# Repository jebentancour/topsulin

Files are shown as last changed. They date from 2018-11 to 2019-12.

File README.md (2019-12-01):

# Topsulin

## Software

### BLE Services and Characteristics

|GATT Services |GATT Characteristics |Description |
|---|---|---|
|**Glucose** |0x1808 |Servicio estándar para glucómetros |
|0x2A18 |**Glucose Measurement** |Valores de glucemia |
|0x2A34 |**Glucose Measurement Context** |Información adicional (CHO e insulina) |
|0x2A51 |**Glucose Feature** |Información sobre features soportadas |
|0x2A52 |**Record Access Control Point** |Punto de control de acceso del registro  |
|**Topsulin**  |0xF65D |Servicio específico de Topsulin |
|0xF65E |**Configuration** |Configuración de preferencias de usuario |
|0xF65F |**Name** |Nombre para mostrar |
|0xF660 |**Time** |Fecha y hora |
|0xF661 |**Calculator** |Parámetros para el calculador de bolos |
|0xF662 |**Insulin** |Tipo, capacidad y cantidad restante |
|0xF663 |**Device** |Información sobre el dispositivo |

Base UUID para Topsulin Services y Characteristics 0x3419-XXXX-1505-31A7-EC4D-449B-0752-1104

#### Glucose Service

Según el servicio estándar [Glucose Service Specification](https://www.bluetooth.com/specifications/gatt/viewer?attributeXmlFile=org.bluetooth.service.glucose.xml)

Definimos que 1 U de insulina se representa como 10 ml.

```c
/**@brief Glucose feature */
#define BLE_GLS_FEATURE_LOW_BATT                       0x0001  /**< Low Battery Detection During Measurement Supported */
#define BLE_GLS_FEATURE_MALFUNC                        0x0002  /**< Sensor Malfunction Detection Supported */
#define BLE_GLS_FEATURE_SAMPLE_SIZE                    0x0004  /**< Sensor Sample Size Supported */
#define BLE_GLS_FEATURE_INSERT_ERR                     0x0008  /**< Sensor Strip Insertion Error Detection Supported */
#define BLE_GLS_FEATURE_TYPE_ERR                       0x0010  /**< Sensor Strip Type Error Detection Supported */
#define BLE_GLS_FEATURE_RES_HIGH_LOW                   0x0020  /**< Sensor Result High-Low Detection Supported */
#define BLE_GLS_FEATURE_TEMP_HIGH_LOW                  0x0040  /**< Sensor Temperature High-Low Detection Supported */
#define BLE_GLS_FEATURE_READ_INT                       0x0080  /**< Sensor Read Interrupt Detection Supported */
#define BLE_GLS_FEATURE_GENERAL_FAULT                  0x0100  /**< General Device Fault Supported */
#define BLE_GLS_FEATURE_TIME_FAULT                     0x0200  /**< Time Fault Supported */
#define BLE_GLS_FEATURE_MULTI_BOND                     0x0400  /**< Multiple Bond Supported */

/**@brief Glucose measurement flags */
#define BLE_GLS_MEAS_FLAG_TIME_OFFSET                  0x01    /**< Time Offset Present */
#define BLE_GLS_MEAS_FLAG_CONC_TYPE_LOC                0x02    /**< Glucose Concentration, Type, and Sample Location Present */
#define BLE_GLS_MEAS_FLAG_UNITS_KG_L                   0x00    /**< Glucose Concentration Units kg/L */
#define BLE_GLS_MEAS_FLAG_UNITS_MOL_L                  0x04    /**< Glucose Concentration Units mol/L */
#define BLE_GLS_MEAS_FLAG_SENSOR_STATUS                0x08    /**< Sensor Status Annunciation Present */
#define BLE_GLS_MEAS_FLAG_CONTEXT_INFO                 0x10    /**< Context Information Follows */

/**@brief Glucose measurement type */
#define BLE_GLS_MEAS_TYPE_CAP_BLOOD                    1       /**< Capillary whole blood */
#define BLE_GLS_MEAS_TYPE_CAP_PLASMA                   2       /**< Capillary plasma */
#define BLE_GLS_MEAS_TYPE_VEN_BLOOD                    3       /**< Venous whole blood */
#define BLE_GLS_MEAS_TYPE_VEN_PLASMA                   4       /**< Venous plasma */
#define BLE_GLS_MEAS_TYPE_ART_BLOOD                    5       /**< Arterial whole blood */
#define BLE_GLS_MEAS_TYPE_ART_PLASMA                   6       /**< Arterial plasma */
#define BLE_GLS_MEAS_TYPE_UNDET_BLOOD                  7       /**< Undetermined whole blood */
#define BLE_GLS_MEAS_TYPE_UNDET_PLASMA                 8       /**< Undetermined plasma */
#define BLE_GLS_MEAS_TYPE_FLUID                        9       /**< Interstitial fluid (ISF) */
#define BLE_GLS_MEAS_TYPE_CONTROL                      10      /**< Control solution */

/**@brief Glucose measurement location */
#define BLE_GLS_MEAS_LOC_FINGER                        1       /**< Finger */
#define BLE_GLS_MEAS_LOC_AST                           2       /**< Alternate Site Test (AST) */
#define BLE_GLS_MEAS_LOC_EAR                           3       /**< Earlobe */
#define BLE_GLS_MEAS_LOC_CONTROL                       4       /**< Control solution */
#define BLE_GLS_MEAS_LOC_NOT_AVAIL                     15      /**< Sample Location value not available */

/**@brief Glucose sensor status annunciation */
#define BLE_GLS_MEAS_STATUS_BATT_LOW                   0x0001  /**< Device battery low at time of measurement */
#define BLE_GLS_MEAS_STATUS_SENSOR_FAULT               0x0002  /**< Sensor malfunction or faulting at time of measurement */
#define BLE_GLS_MEAS_STATUS_SAMPLE_SIZE                0x0004  /**< Sample size for blood or control solution insufficient at time of measurement */
#define BLE_GLS_MEAS_STATUS_STRIP_INSERT               0x0008  /**< Strip insertion error */
#define BLE_GLS_MEAS_STATUS_STRIP_TYPE                 0x0010  /**< Strip type incorrect for device */
#define BLE_GLS_MEAS_STATUS_RESULT_HIGH                0x0020  /**< Sensor result higher than the device can process */
#define BLE_GLS_MEAS_STATUS_RESULT_LOW                 0x0040  /**< Sensor result lower than the device can process */
#define BLE_GLS_MEAS_STATUS_TEMP_HIGH                  0x0080  /**< Sensor temperature too high for valid test/result at time of measurement */
#define BLE_GLS_MEAS_STATUS_TEMP_LOW                   0x0100  /**< Sensor temperature too low for valid test/result at time of measurement */
#define BLE_GLS_MEAS_STATUS_STRIP_PULL                 0x0200  /**< Sensor read interrupted because strip was pulled too soon at time of measurement */
#define BLE_GLS_MEAS_STATUS_GENERAL_FAULT              0x0400  /**< General device fault has occurred in the sensor */
#define BLE_GLS_MEAS_STATUS_TIME_FAULT                 0x0800  /**< Time fault has occurred in the sensor and time may be inaccurate */

/**@brief Glucose measurement context flags */
#define BLE_GLS_CONTEXT_FLAG_CARB                      0x01    /**< Carbohydrate id and carbohydrate present */
#define BLE_GLS_CONTEXT_FLAG_MEAL                      0x02    /**< Meal present */
#define BLE_GLS_CONTEXT_FLAG_TESTER                    0x04    /**< Tester-health present */
#define BLE_GLS_CONTEXT_FLAG_EXERCISE                  0x08    /**< Exercise duration and exercise intensity present */
#define BLE_GLS_CONTEXT_FLAG_MED                       0x10    /**< Medication ID and medication present */
#define BLE_GLS_CONTEXT_FLAG_MED_KG                    0x00    /**< Medication value units, kilograms */
#define BLE_GLS_CONTEXT_FLAG_MED_L                     0x20    /**< Medication value units, liters */
#define BLE_GLS_CONTEXT_FLAG_HBA1C                     0x40    /**< Hba1c present */
#define BLE_GLS_CONTEXT_FLAG_EXT                       0x80    /**< Extended flags present */

/**@brief Glucose measurement context carbohydrate ID */
#define BLE_GLS_CONTEXT_CARB_BREAKFAST                 1       /**< Breakfast */
#define BLE_GLS_CONTEXT_CARB_LUNCH                     2       /**< Lunch */
#define BLE_GLS_CONTEXT_CARB_DINNER                    3       /**< Dinner */
#define BLE_GLS_CONTEXT_CARB_SNACK                     4       /**< Snack */
#define BLE_GLS_CONTEXT_CARB_DRINK                     5       /**< Drink */
#define BLE_GLS_CONTEXT_CARB_SUPPER                    6       /**< Supper */
#define BLE_GLS_CONTEXT_CARB_BRUNCH                    7       /**< Brunch */

/**@brief Glucose measurement context meal */
#define BLE_GLS_CONTEXT_MEAL_PREPRANDIAL               1       /**< Preprandial (before meal) */
#define BLE_GLS_CONTEXT_MEAL_POSTPRANDIAL              2       /**< Postprandial (after meal) */
#define BLE_GLS_CONTEXT_MEAL_FASTING                   3       /**< Fasting */
#define BLE_GLS_CONTEXT_MEAL_CASUAL                    4       /**< Casual (snacks, drinks, etc.) */
#define BLE_GLS_CONTEXT_MEAL_BEDTIME                   5       /**< Bedtime */

/**@brief Glucose measurement context tester */
#define BLE_GLS_CONTEXT_TESTER_SELF                    1       /**< Self */
#define BLE_GLS_CONTEXT_TESTER_PRO                     2       /**< Health care professional */
#define BLE_GLS_CONTEXT_TESTER_LAB                     3       /**< Lab test */
#define BLE_GLS_CONTEXT_TESTER_NOT_AVAIL               15      /**< Tester value not available */

/**@brief Glucose measurement context health */
#define BLE_GLS_CONTEXT_HEALTH_MINOR                   1       /**< Minor health issues */
#define BLE_GLS_CONTEXT_HEALTH_MAJOR                   2       /**< Major health issues */
#define BLE_GLS_CONTEXT_HEALTH_MENSES                  3       /**< During menses */
#define BLE_GLS_CONTEXT_HEALTH_STRESS                  4       /**< Under stress */
#define BLE_GLS_CONTEXT_HEALTH_NONE                    5       /**< No health issues */
#define BLE_GLS_CONTEXT_HEALTH_NOT_AVAIL               15      /**< Health value not available */

/**@brief Glucose measurement context medication ID */
#define BLE_GLS_CONTEXT_MED_RAPID                      1       /**< Rapid acting insulin */
#define BLE_GLS_CONTEXT_MED_SHORT                      2       /**< Short acting insulin */
#define BLE_GLS_CONTEXT_MED_INTERMED                   3       /**< Intermediate acting insulin */
#define BLE_GLS_CONTEXT_MED_LONG                       4       /**< Long acting insulin */
#define BLE_GLS_CONTEXT_MED_PREMIX                     5       /**< Pre-mixed insulin */

/**@brief SFLOAT format (IEEE-11073 16-bit FLOAT, meaning 4 bits for exponent (base 10) and 12 bits mantissa) */
typedef struct
{
  int8_t exponent;                                             /**< Base 10 exponent, should be using only 4 bits */
  int16_t mantissa;                                            /**< Mantissa, should be using only 12 bits */
} sfloat_t;
```

Los enteros de 16 bits se codifican de manera que el byte más alto va primero. El número 250 en hexadecimal es 0x00FA, sin embargo en BLE se lee el byte 0xFA00.

El sfloat se usa para guardar un número con coma en 16 bits, los primeros 12 bits son la mantisa y los otros 4 el exponente.

```c
uint16_t encode_sfloat(sfloat_t sf)
{
    uint16_t dec;
    dec = ((sf.exponent << 12) & 0xF000) | ((sf.mantissa <<  0) & 0x0FFF);
    return dec;
}

sfloat_t decode_sfloat(uint16_t u)
{
    sfloat_t sf;
    sf.exponent = (u & 0xF000) >> 12;
    sf.mantissa = (u & 0x0FFF) >> 0;
    return sf;
}
```

#### Topsulin Service

[Characteristic Format Types](https://www.bluetooth.com/specifications/assigned-numbers/format-types)

|Characteristic |Format |Value |Default |
|---|---|---|---|
|**Configuration** | | | |
|Registro de glucemia |bit0 |0 No, 1 Si |Si |
|Registro de insulina |bit1 |0 No, 1 Si |Si |
|Registro de CHO |bit2 |0 No, 1 Si |Si |
|Invertir los colores de la pantalla |bit3 |0 Fondo blanco, 1 Fondo negro |Fondo blanco |
|Unidades de glucemia |bit4 |0 kg/L, 1 mol/L |kg/L |
|Calculador de bolo |bit5 |0 Desactivado, 1 Activado |Desactivado |
|Orientación de pantalla |bit6 |0 Diestro, 1 Zurdo |Diestro |
|Unidades de CHO |bit7 |0 CHO en g, 1 CHO en porciones |CHO en g |
|Equivalencia entre gramos y porciones |uint16 |Peso en g de una porción |250 g |
|Incremento de CHO |uint8  |Paso de ingreso de CHO en g |5 g |
|Incremento de insulina |uint8  |Paso de ingreso de insulina x10 |10 (equivale a 1U) |
|**Name** | | | |
|Nombre para mostrar |uint8  |String de largo máximo 20 UTF-8 |Glucosee |
|**Time** | | | |
|Hora y fecha del dispositivo |time |[Time Characteristic](https://www.bluetooth.com/specifications/gatt/viewer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) |01/01/19 12:00:00 |
|**Calculator** | | | |
|Nivel bajo |sfloat |Nivel de glucemia baja en kg/L |90x10^-5 kg/L |
|Nivel alto |sfloat |Nivel de glucemia alta en kg/L |150x10^-5 kg/L |
|Sensibilidad |uint16 |Cada cuántos CHO en g incremento insulina |15 g |
|Corrección de hiperglucemia |sfloat |Cada cuántos kg/L de hiper incremento insulina |50x10^-5 kg/L |
|**Insulin** | | | |
|Tipo de insulina |uint8  |Medication ID from Glucose Service |BLE_GLS_CONTEXT_MED_RAPID |
|Capacidad de la lapicera |uint16 |U de insulina en una lapicera nueva|300 U |
|Capacidad restante de la lapicera |uint16 |U de insulina restantes |120 U |
|Comienzo de acción |uint16 |En minutos |30 m |
|Acción máxima |uint16 |En minutos |120 m |
|Duración de la acción |uint16 |En minutos |360 m |
|**Device** | | | |
|Firmware |uint8  |Versión de firmware |1 |
|Serial Number |uint16 |Número de serie |1 |
|Battery |uint16 |Voltaje de la batería en mV |Cerca de 3300 mV |

## Board

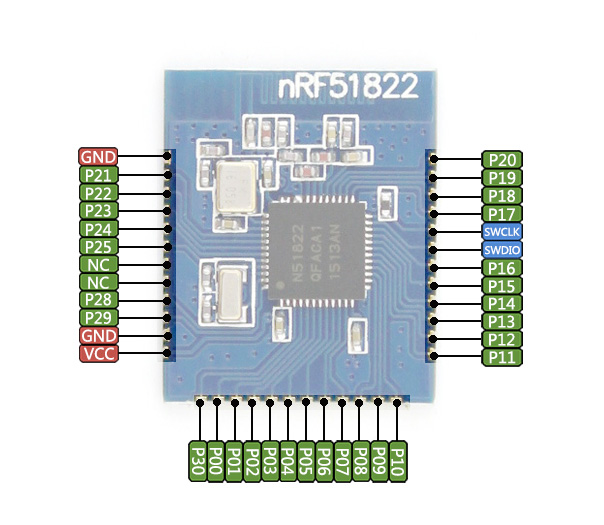
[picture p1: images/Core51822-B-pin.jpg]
pinout


## Encoder

|nRF pin|Use  |
|---|-----|
|01 |A |
|00 |B |
|30 |SW |

## Display

|nRF pin|Use  |
|---|-----|
|21 |MOSI |
|22 |CLK  |
|23 |CS |
|24 |DC |
|25 |RST  |
|28 |BUSY |

## SoC

SoC [nRF51822](https://www.nordicsemi.com/eng/nordic/download_resource/62726/14/39584073/13358) QFACA10 (256kB flash, 32 kB RAM)

[INFOCENTER](http://infocenter.nordicsemi.com)

|ID |Base address |Peripheral  |Instance |Description |Used by |
|---|---|---|---|---|---|
|0  |0x40000000 |POWER |POWER |Power Control. |SoftDevice |
|0  |0x40000000 |CLOCK |CLOCK |Clock Control. |SoftDevice |
|0  |0x40000000 |MPU |MPU |Memory Protection Unit. |SoftDevice |
|1  |0x40001000 |RADIO |RADIO |2.4 GHz Radio. |SoftDevice |
|2  |0x40002000 |UART |UART0 |Universal Asynchronous Receiver/Transmitter. | |
|3  |0x40003000 |SPI |SPI0 |SPI Master. |EPD (SPI) |
|3  |0x40003000 |TWI |TWI0 |I2C compatible Two-Wire Interface 0. |EPD (SPI) |
|4  |0x40004000 |SPIS |SPIS1 |SPI Slave. | |
|4  |0x40004000 |SPI |SPI1 |SPI Master. | |
|4  |0x40004000 |TWI |TWI1 |I2C compatible Two-Wire Interface 1. | |
|6  |0x40006000 |GPIOTE |GPIOTE |GPIO Task and Events. | |
|7  |0x40007000 |ADC |ADC |Analog to Digital Converter. |Battery |
|8  |0x40008000 |TIMER |TIMER0 |Timer/Counter 0. |SoftDevice |
|9  |0x40009000 |TIMER |TIMER1 |Timer/Counter 1. | |
|10 |0x4000A000 |TIMER |TIMER2 |Timer/Counter 2. | |
|11 |0x4000B000 |RTC |RTC0 |Real Time Counter 0. |SoftDevice |
|12 |0x4000C000 |TEMP |TEMP |Temperature Sensor. |SoftDevice |
|13 |0x4000D000 |RNG |RNG |Random Number Generator. |SoftDevice |
|14 |0x4000E000 |ECB |ECB |Crypto AES ECB. |SoftDevice |
|15 |0x4000F000 |CCM |CCM |AES Crypto CCM. |SoftDevice |
|15 |0x4000F000 |AAR |AAR |Accelerated Address Resolver. |SoftDevice |
|16 |0x40010000 |WDT |WDT |Watchdog Timer. | |
|17 |0x40011000 |RTC |RTC1 |Real Time Counter 1. |Timer library |
|18 |0x40012000 |QDEC |QDEC |Quadrature Decoder. |Encoder |
|19 |0x40013000 |LPCOMP |LPCOMP |Low Power Comparator. | |
|20 |0x40014000 |SWI |SWI0 |Software interrupt. |Timer library |
|21 |0x40015000 |SWI |SWI1 |Software interrupt. |SoftDevice |
|22 |0x40016000 |SWI |SWI2 |Software interrupt |SoftDevice |
|23 |0x40017000 |SWI |SWI3 |Software interrupt. | |
|24 |0x40018000 |SWI |SWI4 |Software interrupt. |SoftDevice |
|25 |0x40019000 |SWI |SWI5 |Software interrupt. |SoftDevice |
|30 |0x4001E000 |NVMC |NVMC |Non-Volatile Memory Controller. |SoftDevice |
|31 |0x4001F000 |PPI |PPI |Programmable Peripheral Interconnect. | |
|NA |0x50000000 |GPIO |GPIO |General Purpose Input and Output. |Gpio |
|NA |0x10000000 |FICR |FICR |Factory Information Configuration Registers. |SoftDevice |
|NA |0x10001000 |UICR |UICR |User Information Configuration Registers. |SoftDevice |

## EPD

[Image file to embedded C/C++ code](https://digole.com/tools/PicturetoC_Hex_converter.php)

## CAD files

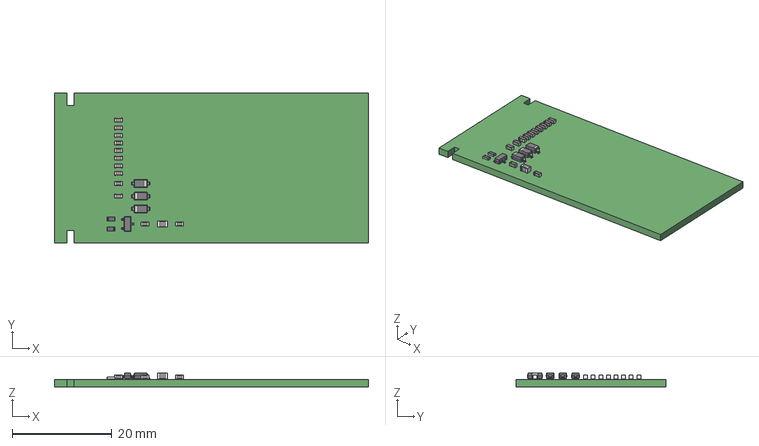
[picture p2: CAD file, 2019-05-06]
pcb/pcb_topsulin_base.step
63.0 x 30.0 x 2.90 mm

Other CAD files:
pcb/pcb_topsulin.step

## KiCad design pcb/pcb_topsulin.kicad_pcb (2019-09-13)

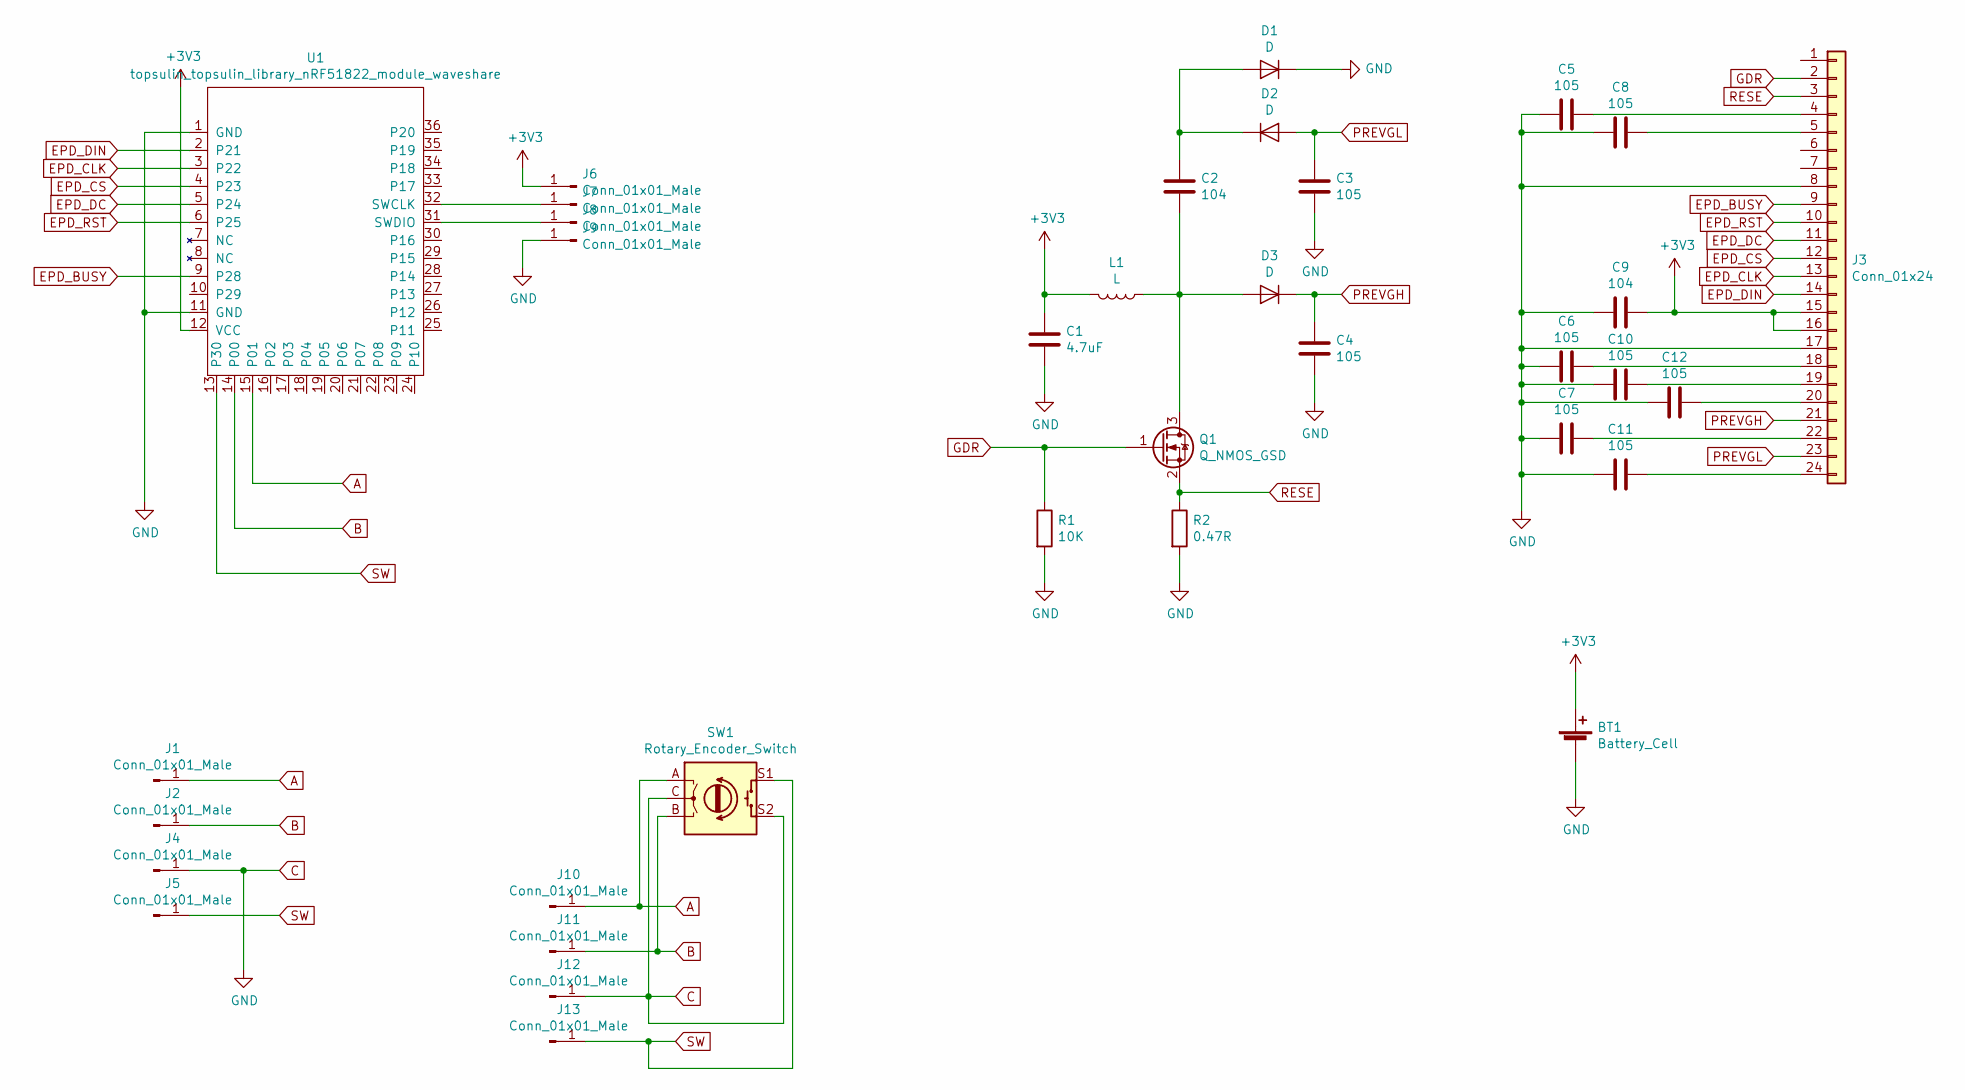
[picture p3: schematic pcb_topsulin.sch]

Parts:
BT1: Battery_Cell; BatteryHolder_Keystone_1058_1x2032
C1: 4.7uF; C_0603_1608Metric
C2, C9: 104; C_0603_1608Metric
C3, C4, C5, C6, C7, C8, C10, C11, C12: 105; C_0603_1608Metric
D1, D2, D3: D; D_SOD-123
J1, J2, J4, J5, J10, J11, J12, J13: Conn_01x01_Male; TestPoint_Pad_2.0x2.0mm
J3: Conn_01x24; e-paper-2in13-flex
J6, J7, J8, J9: Conn_01x01_Male; TestPoint_Pad_1.0x1.0mm
L1: L; L_0805_2012Metric
Q1: Q_NMOS_GSD; SOT-23
R1: 10K; R_0603_1608Metric
R2: 0.47R; R_0603_1608Metric
SW1: Rotary_Encoder_Switch; RotaryEncoder_Alps_EC12E-Switch_Vertical_H20mm
U1: topsulin_topsulin_library_nRF51822_module_wavesha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; nRF51822_module_waveshare_footprint

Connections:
+3V3: BT1.1 (+), C1.1, C9.1, J3.15, J3.16, J6.1, L1.2, U1.12 (VCC)
A: J1.1, J10.1, SW1.A, U1.15 (P01)
B: J2.1, J11.1, SW1.B, U1.14 (P00)
C: BT1.2 (-), C1.2, C3.2, C4.2, C5.2, C6.2, C7.2, C8.2, C9.2, C10.2, C11.2, C12.2, D1.1 (K), J3.8, J3.17, J4.1, J9.1, J12.1, R1.2, R2.2, SW1.C, SW1.S2, U1.1 (GND), U1.11 (GND)
EPD_BUSY: J3.9, U1.9 (P28)
EPD_CLK: J3.13, U1.3 (P22)
EPD_CS: J3.12, U1.4 (P23)
EPD_DC: J3.11, U1.5 (P24)
EPD_DIN: J3.14, U1.2 (P21)
EPD_RST: J3.10, U1.6 (P25)
GDR: J3.2, Q1.1 (G), R1.1
unnamed: C2.1, D1.2 (A), D2.1 (K)
unnamed: C2.2, D3.2 (A), L1.1, Q1.3 (D)
unnamed: C5.1, J3.4
unnamed: C6.1, J3.18
unnamed: C7.1, J3.22
unnamed: C8.1, J3.5
unnamed: C10.1, J3.19
unnamed: C11.1, J3.24
unnamed: C12.1, J3.20
unnamed: J7.1, U1.32 (SWCLK)
unnamed: J8.1, U1.31 (SWDIO)
PREVGH: C4.1, D3.1 (K), J3.21
PREVGL: C3.1, D2.2 (A), J3.23
RESE: J3.3, Q1.2 (S), R2.1
SW: J5.1, J13.1, SW1.S1, U1.13 (P30)

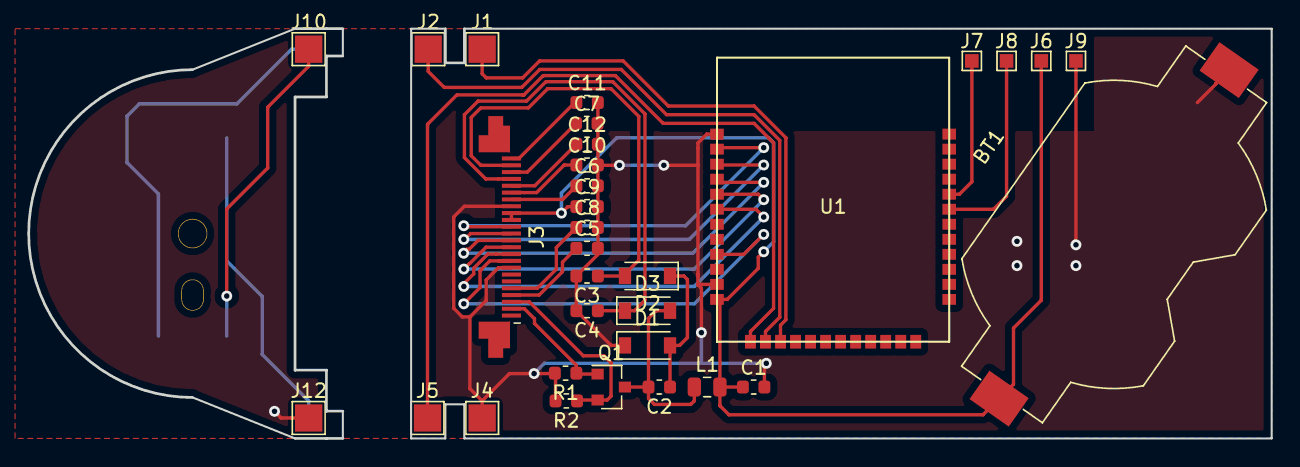
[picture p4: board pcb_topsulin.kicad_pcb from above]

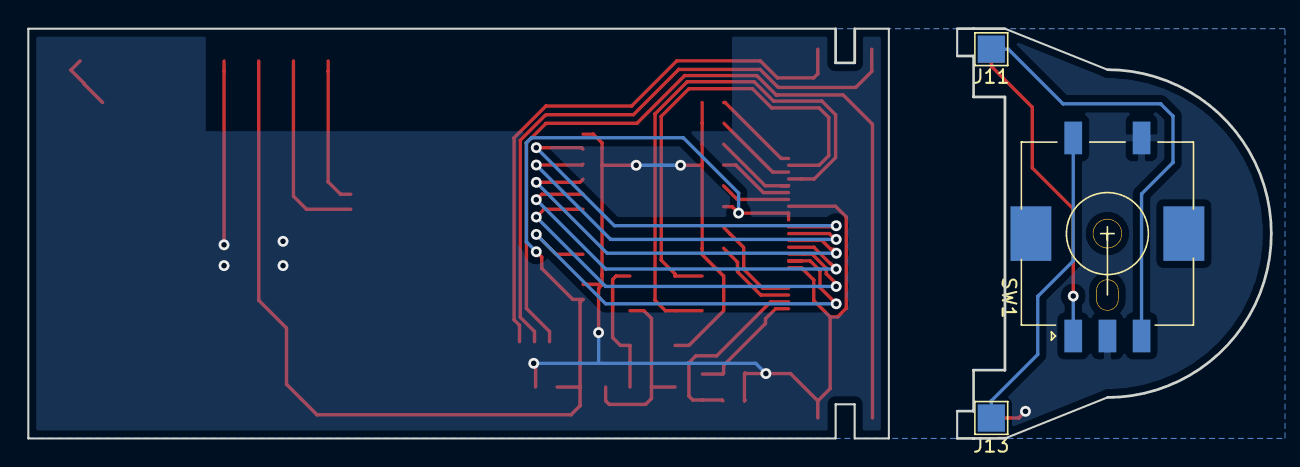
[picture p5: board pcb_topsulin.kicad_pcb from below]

Board: 2 copper layers, 63.0 x 30.0 mm, 35 parts (3 on the bottom side), 26 nets.

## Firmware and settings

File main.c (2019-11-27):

#include <stdio.h>
#include <stdbool.h>

#include "nrf_delay.h"

#define NRF_LOG_MODULE_NAME "MAIN"

#include "nrf_log.h"
#include "nrf_log_ctrl.h"

#include "FEPD_2in13.h"
#include "GUI_Paint.h"
#include "GUI_Cache.h"
#include "ImageData.h"
#include "clock.h"
#include "gpio.h"
#include "ble_services.h"
#include "encoder.h"
#include "state.h"
#include "batt.h"
#include "config_manager.h"

#define IDLE_S          60
#define IDLE_TICKS      (IDLE_S * 1000)/CLOCK_TICK_MS

volatile uint8_t clock_tick_flag;
volatile uint8_t button_flag;
volatile uint8_t long_button_flag;
volatile uint8_t long_long_button_flag;
volatile uint8_t double_button_flag;
volatile uint8_t encoder_flag;
volatile uint8_t batt_flag;
volatile uint8_t display_flag;
volatile uint8_t idle_flag;

uint8_t wake_up;
uint16_t idle_timer;

int main(void){

    NRF_LOG_INIT(clock_get_timestamp);

    struct tm m_tm;
    m_tm.tm_year = 2019 - 1900;
    m_tm.tm_mon = 1 - 1;
    m_tm.tm_mday = 1;
    m_tm.tm_hour = 12;
    m_tm.tm_min = 00;
    m_tm.tm_sec = 0;
    clock_set_time(&m_tm);

    display_flag = 0;
    state_display_set_flag(&display_flag);
    idle_flag = 0;
    state_idle_set_flag(&idle_flag);
    state_init();

    config_manager_init();
    //config_manager_print();

    sd_power_mode_set(NRF_POWER_MODE_LOWPWR);
    ble_services_init();

    clock_tick_flag = 0;
    clock_tick_set_flag(&clock_tick_flag);
    clock_init();

    uint32_t last = 0;
    uint32_t now = 0;

    UWORD color;
    if (config_manager_get_flags() & CONFIG_COLOR_FLAG){
      color = WHITE;
    } else {
      color = BLACK;
    }

    DEV_ModuleInit();
    EPD_Init(FULL_UPDATE);
    Paint_NewImage(ImageBuff, EPD_WIDTH, EPD_HEIGHT, ROTATE_90, color);
    Paint_DrawBitMap(gImage_initial);
    EPD_DisplayWindows(ImageBuff, 0, 0, EPD_WIDTH, EPD_HEIGHT);
    EPD_TurnOnDisplay();
    EPD_Sleep();
    DEV_ModuleUninit();

    batt_flag = 0;
    batt_set_flag(&batt_flag);
    batt_init();
    batt_sample();
    while(!batt_flag){
        // wait...
    }
    batt_flag = 0;
    uint32_t voltage;
    voltage = batt_get();
    NRF_LOG_INFO("VCC = %d.%d V\n", voltage / 1000, voltage % 1000);

    button_flag = 0;
    gpio_button_set_flag(&button_flag);
    long_button_flag = 0;
    gpio_long_button_set_flag(&long_button_flag);
    long_long_button_flag = 0;
    gpio_long_long_button_set_flag(&long_long_button_flag);
    double_button_flag = 0;
    gpio_double_button_set_flag(&double_button_flag);
    gpio_init();

    encoder_flag = 0;
    encoder_set_flag(&encoder_flag);
    encoder_set_direction((config_manager_get_flags() & CONFIG_FLIP_FLAG) == 0);
    encoder_init();

    wake_up = 1;
    idle_timer = IDLE_TICKS;
    last = clock_get_timestamp();

    NRF_LOG_FLUSH();

    while (true){

        gpio_process(); // GPIO polling

        if(button_flag){
            button_flag = 0;
            if (!wake_up) {
                NRF_LOG_INFO("Wake up from click!\r\n");
                NRF_LOG_FLUSH();
                encoder_enable();
                batt_init();
                wake_up = 1;
            }
            state_on_event(button_pressed);
            idle_timer = 0;
        }

        if(double_button_flag){
            double_button_flag = 0;
            if (wake_up) state_on_event(double_button_pressed);
            idle_timer = 0;
        }

        if(long_button_flag){
            long_button_flag = 0;
            if (wake_up) state_on_event(long_button_pressed);
            idle_timer = 0;
        }

        if(long_long_button_flag){
            long_long_button_flag = 0;
            advertising_toggle();
        }

        if(encoder_flag){
            encoder_flag = 0;
            if (wake_up) state_on_event(encoder_update);
            idle_timer = 0;
        }

        if(clock_tick_flag){
            clock_tick_flag = 0;
            if (wake_up){
              // Update BLE Time and Voltage Characteristics every second
              now = clock_get_timestamp();
              if (now - last >= 1000){
                last = now;
                time_ble_update();
                if(!batt_flag){
                  batt_sample();
                }
              }
              idle_timer++;
            }
        }

        if(batt_flag){
          batt_flag = 0;
          if (wake_up) batt_ble_update((uint16_t)batt_get());
        }

        if(idle_flag){
          idle_flag = 0;
          idle_timer = IDLE_TICKS;
        }

        if(idle_timer >= IDLE_TICKS){
            // prepare to sleep
            if (wake_up){
              NRF_LOG_INFO("Idle timeout\r\n");
              NRF_LOG_FLUSH();
              state_sleep();
              encoder_disable();
              batt_disable();
              wake_up = 0;
            }
            idle_timer = IDLE_TICKS;
        }

        if(display_flag){
          display_flag = 0;
          state_process_display();
        }

        // If it is nothing to do...
        if(!button_flag && !double_button_flag && !long_button_flag && !long_long_button_flag && !encoder_flag && !clock_tick_flag && !batt_flag && !idle_flag && !display_flag){
            // sleep and wait for event...
            sd_app_evt_wait();
        }
    }
}

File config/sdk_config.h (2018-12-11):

#ifndef SDK_CONFIG_H
#define SDK_CONFIG_H
// <<< Use Configuration Wizard in Context Menu >>>\n
#ifdef USE_APP_CONFIG
#include "app_config.h"
#endif
// <h> nRF_BLE

//==========================================================
// <q> BLE_ADVERTISING_ENABLED  - ble_advertising - Advertising module


#ifndef BLE_ADVERTISING_ENABLED
#define BLE_ADVERTISING_ENABLED 1
#endif

// <q> BLE_DTM_ENABLED  - ble_dtm - Module for testing RF/PHY using DTM commands


#ifndef BLE_DTM_ENABLED
#define BLE_DTM_ENABLED 0
#endif

// <q> BLE_RACP_ENABLED  - ble_racp - Record Access Control Point library


#ifndef BLE_RACP_ENABLED
#define BLE_RACP_ENABLED 1
#endif

// <q> NRF_BLE_QWR_ENABLED  - nrf_ble_qwr - Queued writes support module (prepare/execute write)


#ifndef NRF_BLE_QWR_ENABLED
#define NRF_BLE_QWR_ENABLED 0
#endif

// <q> PEER_MANAGER_ENABLED  - peer_manager - Peer Manager


#ifndef PEER_MANAGER_ENABLED
#define PEER_MANAGER_ENABLED 1
#endif

// </h>
//==========================================================

// <h> nRF_BLE_Services

//==========================================================
// <q> BLE_ANCS_C_ENABLED  - ble_ancs_c - Apple Notification Service Client


#ifndef BLE_ANCS_C_ENABLED
#define BLE_ANCS_C_ENABLED 0
#endif

// <q> BLE_ANS_C_ENABLED  - ble_ans_c - Alert Notification Service Client


#ifndef BLE_ANS_C_ENABLED
#define BLE_ANS_C_ENABLED 0
#endif

// <q> BLE_BAS_C_ENABLED  - ble_bas_c - Battery Service Client


#ifndef BLE_BAS_C_ENABLED
#define BLE_BAS_C_ENABLED 0
#endif

// <q> BLE_BAS_ENABLED  - ble_bas - Battery Service


#ifndef BLE_BAS_ENABLED
#define BLE_BAS_ENABLED 0
#endif

// <q> BLE_CSCS_ENABLED  - ble_cscs - Cycling Speed and Cadence Service


#ifndef BLE_CSCS_ENABLED
#define BLE_CSCS_ENABLED 0
#endif

// <q> BLE_CTS_C_ENABLED  - ble_cts_c - Current Time Service Client


#ifndef BLE_CTS_C_ENABLED
#define BLE_CTS_C_ENABLED 0
#endif

// <q> BLE_DIS_ENABLED  - ble_dis - Device Information Service


#ifndef BLE_DIS_ENABLED
#define BLE_DIS_ENABLED 0
#endif

// <q> BLE_GLS_ENABLED  - ble_gls - Glucose Service


#ifndef BLE_GLS_ENABLED
#define BLE_GLS_ENABLED 1
#endif

// <q> BLE_HIDS_ENABLED  - ble_hids - Human Interface Device Service


#ifndef BLE_HIDS_ENABLED
#define BLE_HIDS_ENABLED 0
#endif

// <e> BLE_HRS_C_ENABLED - ble_hrs_c - Heart Rate Service Client
//==========================================================
#ifndef BLE_HRS_C_ENABLED
#define BLE_HRS_C_ENABLED 0
#endif
#if  BLE_HRS_C_ENABLED
// <o> BLE_HRS_C_RR_INTERVALS_MAX_CNT - Maximum number of RR_INTERVALS per notification to be decoded
#ifndef BLE_HRS_C_RR_INTERVALS_MAX_CNT
#define BLE_HRS_C_RR_INTERVALS_MAX_CNT 30
#endif

#endif //BLE_HRS_C_ENABLED
// </e>

// <q> BLE_HRS_ENABLED  - ble_hrs - Heart Rate Service


#ifndef BLE_HRS_ENABLED
#define BLE_HRS_ENABLED 0
#endif

// <q> BLE_HTS_ENABLED  - ble_hts - Health Thermometer Service


#ifndef BLE_HTS_ENABLED
#define BLE_HTS_ENABLED 0
#endif

// <q> BLE_IAS_C_ENABLED  - ble_ias_c - Immediate Alert Service Client


#ifndef BLE_IAS_C_ENABLED
#define BLE_IAS_C_ENABLED 0
#endif

// <q> BLE_IAS_ENABLED  - ble_ias - Immediate Alert Service


#ifndef BLE_IAS_ENABLED
#define BLE_IAS_ENABLED 0
#endif

// <q> BLE_LBS_C_ENABLED  - ble_lbs_c - Nordic LED Button Service Client


#ifndef BLE_LBS_C_ENABLED
#define BLE_LBS_C_ENABLED 0
#endif

// <q> BLE_LBS_ENABLED  - ble_lbs - LED Button Service


#ifndef BLE_LBS_ENABLED
#define BLE_LBS_ENABLED 0
#endif

// <q> BLE_LLS_ENABLED  - ble_lls - Link Loss Service


#ifndef BLE_LLS_ENABLED
#define BLE_LLS_ENABLED 0
#endif

// <q> BLE_NUS_C_ENABLED  - ble_nus_c - Nordic UART Central Service


#ifndef BLE_NUS_C_ENABLED
#define BLE_NUS_C_ENABLED 0
#endif

// <q> BLE_NUS_ENABLED  - ble_nus - Nordic UART Service


#ifndef BLE_NUS_ENABLED
#define BLE_NUS_ENABLED 0
#endif

// <q> BLE_RSCS_C_ENABLED  - ble_rscs_c - Running Speed and Cadence Client


#ifndef BLE_RSCS_C_ENABLED
#define BLE_RSCS_C_ENABLED 0
#endif

// <q> BLE_RSCS_ENABLED  - ble_rscs - Running Speed and Cadence Service


#ifndef BLE_RSCS_ENABLED
#define BLE_RSCS_ENABLED 0
#endif

// <q> BLE_TPS_ENABLED  - ble_tps - TX Power Service


#ifndef BLE_TPS_ENABLED
#define BLE_TPS_ENABLED 0
#endif

// </h>
//==========================================================

// <h> nRF_Drivers

//==========================================================
// <e> ADC_ENABLED - nrf_drv_adc - Driver for ADC peripheral (nRF51)
//==========================================================
#ifndef ADC_ENABLED
#define ADC_ENABLED 1
#endif
#if  ADC_ENABLED
// <o> ADC_CONFIG_IRQ_PRIORITY  - Interrupt priority


// <i> Priorities 0,2 (nRF51) and 0,1,4,5 (nRF52) are reserved for SoftDevice
// <0=> 0 (highest)
// <1=> 1
// <2=> 2
// <3=> 3

#ifndef ADC_CONFIG_IRQ_PRIORITY
#define ADC_CONFIG_IRQ_PRIORITY 3
#endif
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

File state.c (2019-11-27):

#include "state.h"

#include <stdio.h>
#include <stdbool.h>

#define NRF_LOG_MODULE_NAME "STATE"

#include "nrf_log.h"
#include "nrf_log_ctrl.h"

#include "ble_gls_db.h"

#include "encoder.h"
#include "FEPD_2in13.h"
#include "GUI_Paint.h"
#include "GUI_Cache.h"
#include "ImageData.h"
#include "ble_services.h"
#include "clock.h"
#include "batt.h"
#include "config_manager.h"

#define LOW_VOLT  2300

#define MARGEN    6
#define ANCHO     250
#define ALTO      122

typedef enum {
    initial,
    sleep,
    input_cho,
    input_glu,
    input_ins
} internal_state_t;

typedef struct {
    int32_t glu;
    struct tm glu_time;
    int32_t cho;
    struct tm cho_time;
    int32_t ins;
    struct tm ins_time;
} topsulin_meas_t;

static bool new_ins;
static bool new_cho;
static bool new_glu;

static int cho_correction;
static int glu_correction;

static topsulin_meas_t        m_topsulin_meas;
static topsulin_meas_t        m_prev_topsulin_meas;

static internal_state_t       m_state;

static char                   buffer[16];
static uint8_t                len;

static volatile uint8_t       full_refresh;
static volatile uint8_t       quick_refresh;

static uint32_t               voltage;
static uint8_t                bt_state;

static bool                   clock_set;
static bool                   gls_write;

static char                   pin_buffer[8];
static bool                   show_pin;
static bool                   pin_ok;
static bool                   pin_error;

static volatile uint8_t*      m_idle_flag;
static volatile uint8_t*      m_display_flag;

void state_init(){
  m_state = initial;

  memset(&m_prev_topsulin_meas, 0, sizeof(m_prev_topsulin_meas));
  m_prev_topsulin_meas.glu = 0;
  m_prev_topsulin_meas.cho = 0;
  m_prev_topsulin_meas.ins = 0;
  struct tm t;
  clock_get_time(&t);
  m_prev_topsulin_meas.glu_time = t;
  m_prev_topsulin_meas.cho_time = t;
  m_prev_topsulin_meas.ins_time = t;

  memset(&m_topsulin_meas, 0, sizeof(m_topsulin_meas));
  m_topsulin_meas.glu = 0;
  m_topsulin_meas.cho = 0;
  m_topsulin_meas.ins = 0;
  m_topsulin_meas.glu_time = t;
  m_topsulin_meas.cho_time = t;
  m_topsulin_meas.ins_time = t;

  voltage = 0;
  bt_state = 0;

  full_refresh = false;
  quick_refresh = false;

  clock_set = false;
  gls_write = false;
}

static void state_save_meas(void){
  if (new_glu || new_cho || new_ins){
    struct tm t;
    clock_get_time(&t);

    if (new_glu){
      m_topsulin_meas.glu_time = t;
    }

    if (new_cho){
      m_topsulin_meas.cho_time = t;
    }

    if (new_ins){
      m_topsulin_meas.ins_time = t;
    }

    ble_gls_rec_t rec;

    rec.meas.flags = BLE_GLS_MEAS_FLAG_UNITS_KG_L | BLE_GLS_MEAS_FLAG_SENSOR_STATUS;

    if (new_glu){
      rec.meas.flags |= BLE_GLS_MEAS_FLAG_CONC_TYPE_LOC;
    }

    if (new_cho || new_ins){
      rec.meas.flags |= BLE_GLS_MEAS_FLAG_CONTEXT_INFO;
    }

    rec.meas.base_time.year                 = t.tm_year + 1900;
    rec.meas.base_time.month                = t.tm_mon + 1;
    rec.meas.base_time.day                  = t.tm_mday;
    rec.meas.base_time.hours                = t.tm_hour;
    rec.meas.base_time.minutes              = t.tm_min;
    rec.meas.base_time.seconds              = t.tm_sec;

    if (new_glu){
      rec.meas.glucose_concentration.exponent = -5;
      rec.meas.glucose_concentration.mantissa = m_topsulin_meas.glu;
      rec.meas.type                           = BLE_GLS_MEAS_TYPE_CAP_BLOOD;
      rec.meas.sample_location                = BLE_GLS_MEAS_LOC_NOT_AVAIL;
    }

    rec.meas.sensor_status_annunciation     = 0;
    //rec.meas.sensor_status_annunciation     = BLE_GLS_MEAS_STATUS_BATT_LOW;

    if (new_cho){
      rec.context.flags |= BLE_GLS_CONTEXT_FLAG_CARB;
      if (t.tm_hour <= 4){
          // cena
          rec.context.carbohydrate_id = BLE_GLS_CONTEXT_CARB_DINNER;
      } else {
          if (t.tm_hour <= 11){
              // desayuno
              rec.context.carbohydrate_id = BLE_GLS_CONTEXT_CARB_BREAKFAST;
          } else {
              if (t.tm_hour <= 15){
                  // almuerzo
                  rec.context.carbohydrate_id = BLE_GLS_CONTEXT_CARB_LUNCH;
              } else {
                  if (t.tm_hour <= 19){
                      // merienda
                      rec.context.carbohydrate_id =	BLE_GLS_CONTEXT_CARB_SNACK;
                  } else {
                      // cena
                      rec.context.carbohydrate_id = BLE_GLS_CONTEXT_CARB_DINNER;
                  }
              }
          }
      }
      rec.context.carbohydrate.exponent = 0; // Exponent: Decimal, -3
      rec.context.carbohydrate.mantissa = m_topsulin_meas.cho;
    }

    if (new_ins){
      rec.context.flags |= BLE_GLS_CONTEXT_FLAG_MED;
      rec.context.flags |= BLE_GLS_CONTEXT_FLAG_MED_L;
      rec.context.medication_id         = config_manager_get_insulin_type();
      // Definimos que 1 U de insulina se representa como 10 ml
      rec.context.medication.exponent   = 3; // Exponent: Decimal, -3
      rec.context.medication.mantissa   = m_topsulin_meas.ins;
    }

    CRITICAL_REGION_ENTER();
    add_glucose_measurement(rec);
    CRITICAL_REGION_EXIT();

    if(!new_glu){
        m_topsulin_meas.glu = m_prev_topsulin_meas.glu;
    }

    if(!new_cho || m_topsulin_meas.cho <= 0){
        m_topsulin_meas.cho = m_prev_topsulin_meas.cho;
    }

    if(!new_ins || m_topsulin_meas.ins <= 0){
        m_topsulin_meas.ins = m_prev_topsulin_meas.ins;
    }
  }
}

void state_set_bt_state(uint8_t state){
  NRF_LOG_INFO("state_set_bt_state %d\n", state);
  if (bt_state == state){
    return;
  }
  bt_state = state;
  if (m_state == initial){
    if (state == 0){
      full_refresh = 1;
    }
    if (state == 1){
      quick_refresh = 1;
    }
    if (state == 2){
      quick_refresh = 1;
    }
  } else {
    quick_refresh = 1;
  }
  *m_display_flag = 1;
}

void state_show_pin(char* pin){
  strncpy(pin_buffer, pin, 6);
  show_pin = true;
  pin_ok = false;
  pin_error = false;
  //quick_refresh = 1;
  *m_display_flag = 1;
}

void state_show_pin_error(void){
  show_pin = false;
  pin_ok = false;
  pin_error = true;
  //quick_refresh = 1;
  *m_display_flag = 1;
}

void state_show_pin_ok(void){
  show_pin = false;
  pin_ok = true;
  pin_error = false;
  //quick_refresh = 1;
  *m_display_flag = 1;
}

void state_update_mem(void){
  quick_refresh = 1;
  *m_display_flag = 1;
}

void state_update_config(void){
  if (m_state == initial) return;
  quick_refresh = 1;
  *m_display_flag = 1;
}

void state_idle_set_flag(volatile uint8_t* main_idle_flag){
  m_idle_flag = main_idle_flag;
}

void state_display_set_flag(volatile uint8_t* main_display_flag){
  m_display_flag = main_display_flag;
}
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

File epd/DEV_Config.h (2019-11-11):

#ifndef _DEV_CONFIG_H_
#define _DEV_CONFIG_H_

#include "nrf_gpio.h"
#include "nrf_delay.h"
#include "nrf_drv_spi.h"
#include <stdint.h>

/**
 * data
**/
#define UBYTE   uint8_t
#define UWORD   uint16_t
#define UDOUBLE uint32_t

/**
 * e-Paper GPIO
**/
#define MOSI_PIN        21
#define CLK_PIN         22

#define CS_PIN          23
#define DC_PIN          24
#define RST_PIN         25
#define BUSY_PIN        28

#define EPD_CS_0		nrf_gpio_pin_clear(CS_PIN)
#define EPD_CS_1		nrf_gpio_pin_set(CS_PIN)

#define EPD_DC_0		nrf_gpio_pin_clear(DC_PIN)
#define EPD_DC_1		nrf_gpio_pin_set(DC_PIN)

#define EPD_RST_0		nrf_gpio_pin_clear(RST_PIN)
#define EPD_RST_1		nrf_gpio_pin_set(RST_PIN)

#define EPD_BUSY_RD		nrf_gpio_pin_read(BUSY_PIN)

void DEV_ModuleInit(void);
void DEV_ModuleUninit(void);

UBYTE DEV_SPI_WriteByte(UBYTE value);
UBYTE DEV_SPI_ReadByte(UBYTE value);

void DEV_Delay_ms(UWORD xms);

#endif

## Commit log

2018-10-19 Encoder support
2018-10-25 Battery support
2019-02-11 Encoder update
2019-03-12 Encoder fix, icon update and cho incremet 5
    [encoder.c, main.c, state.c]
2019-04-10 Low battery warning
2019-04-24 Button and state
2019-05-06 Switch to linux
    [pcb_topsulin.kicad_pcb, pcb_topsulin.sch, pcb_topsulin.step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]
2019-05-09 Show device name
2019-09-13 add pcb
    [pcb_topsulin.kicad_pcb, pcb_topsulin.sch]
2019-10-19 calc and battery icons
